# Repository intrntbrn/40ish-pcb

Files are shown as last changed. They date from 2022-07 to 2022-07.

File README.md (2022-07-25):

40-ish (a Bakeneko60 fork)
==================

<p align="center">
  
</p>

<p align="center">
  
</p>

<p align="center">
  
</p>

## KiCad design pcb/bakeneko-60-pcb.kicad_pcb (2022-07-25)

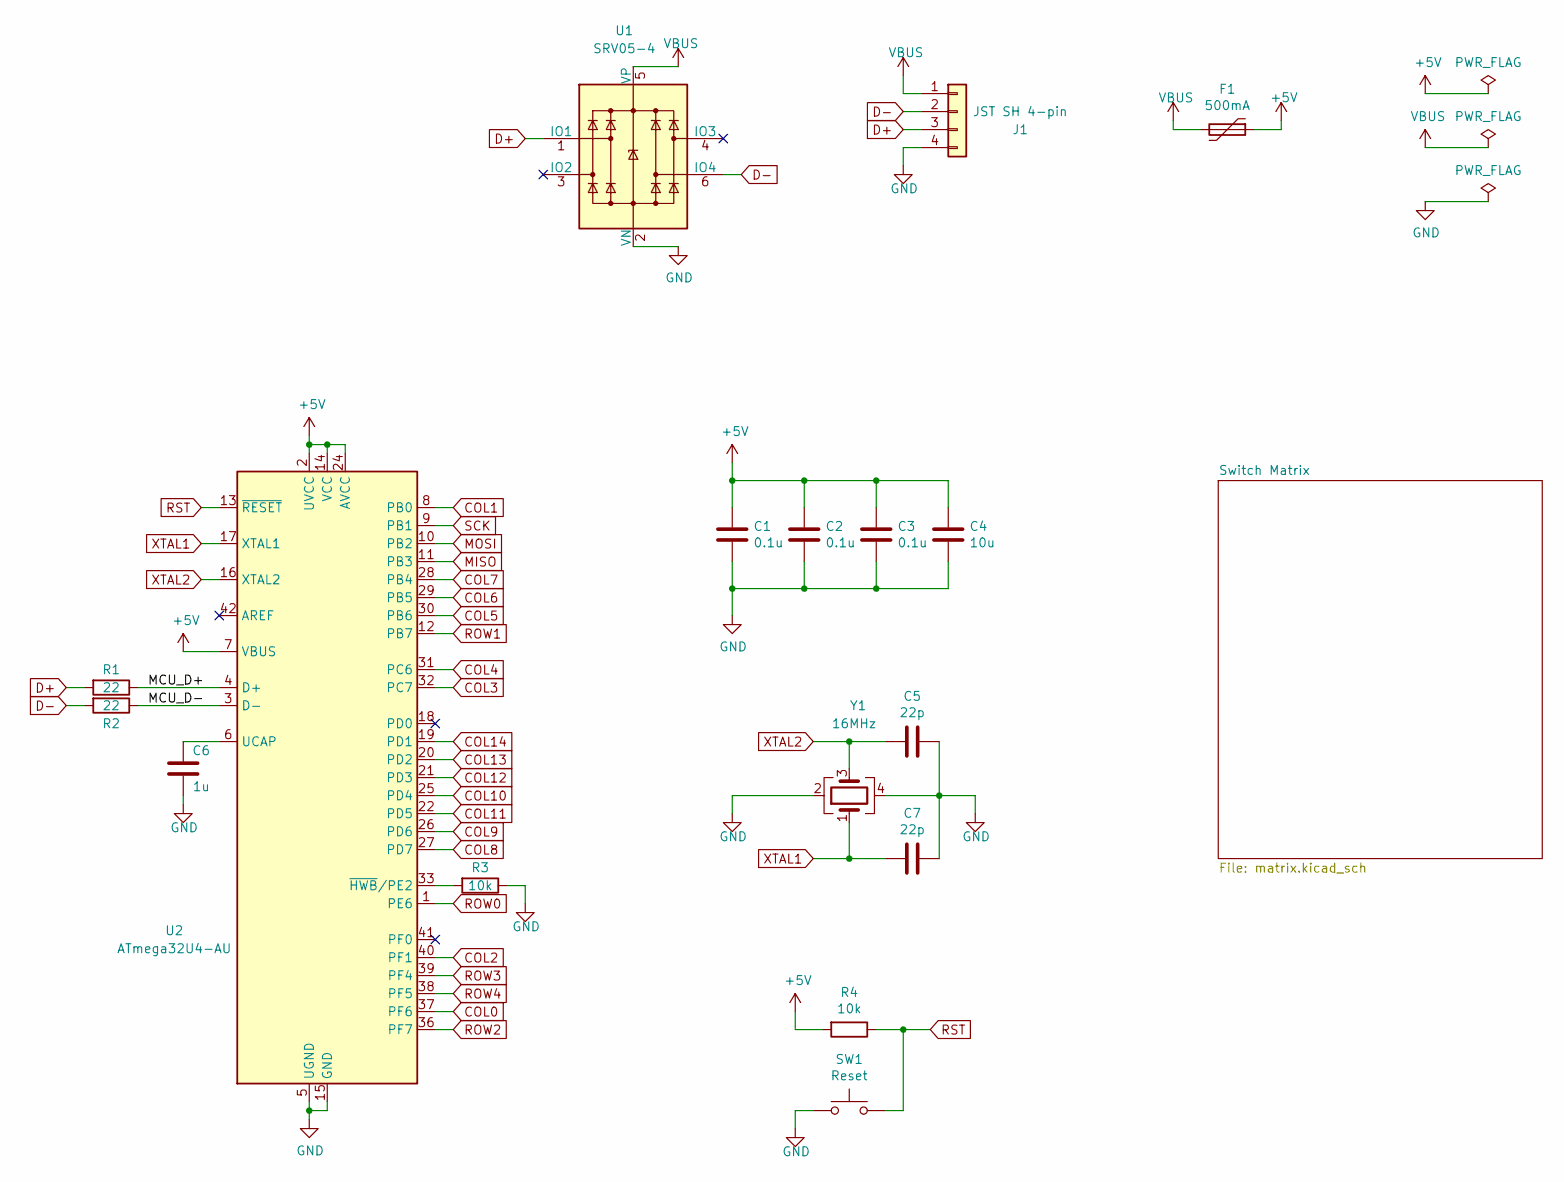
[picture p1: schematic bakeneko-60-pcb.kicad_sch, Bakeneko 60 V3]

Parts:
C1, C2, C3: 0.1u; C_0805_2012Metric; LCSC Part # C49678
C4: 10u; C_0805_2012Metric; LCSC Part # C15850
C5, C7: 22p; C_0805_2012Metric; LCSC Part # C1804
C6: 1u; C_0805_2012Metric; LCSC Part # C28323
F1: 500mA; Fuse_1206_3216Metric; LCSC Part # C70076
J1: JST SH 4-pin; JST_SH_SM04B-SRSS-TB_1x04-1MP_P1.00mm_Horizontal; LCSC Part # C160404
R1, R2: 22; R_0805_2012Metric; LCSC Part # C17561
R3, R4: 10k; R_0805_2012Metric; LCSC Part # C17414
SW1: Reset; SW_SPST_TL3342; LCSC Part # C318884
U1: SRV05-4; SOT-23-6; LCSC Part # C85364
U2: ATmega32U4-AU; TQFP-44_10x10mm_P0.8mm; LCSC Part # C44854
Y1: 16MHz; Crystal_SMD_3225-4Pin_3.2x2.5mm; LCSC Part # C13738

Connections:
+5V: C1.1, C2.1, C3.1, C4.1, F1.1, R4.2, U2.2 (UVCC), U2.7 (VBUS), U2.14 (VCC), U2.24 (AVCC), U2.34 (VCC), U2.44 (AVCC)
/MCU_D+: R1.1, U2.4 (D+)
/MCU_D-: R2.1, U2.3 (D-)
COL0: U2.37 (PF6); also elsewhere on the board
COL1: U2.8 (PB0); also elsewhere on the board
COL2: U2.40 (PF1); also elsewhere on the board
COL3: U2.32 (PC7); also elsewhere on the board
COL4: U2.31 (PC6); also elsewhere on the board
COL5: U2.30 (PB6); also elsewhere on the board
COL6: U2.29 (PB5); also elsewhere on the board
COL7: U2.28 (PB4); also elsewhere on the board
COL8: U2.27 (PD7); also elsewhere on the board
COL9: U2.26 (PD6); also elsewhere on the board
COL10: U2.25 (PD4); also elsewhere on the board
COL11: U2.22 (PD5); also elsewhere on the board
COL12: U2.21 (PD3); also elsewhere on the board
COL13: U2.20 (PD2); also elsewhere on the board
COL14: U2.19 (PD1); also elsewhere on the board
D+: J1.3, R1.2, U1.1 (IO1)
D-: J1.2, R2.2, U1.6 (IO4)
GND: C1.2, C2.2, C3.2, C4.2, C5.1, C6.2, C7.1, J1.4, R3.1, SW1.1, U1.2 (VN), U2.5 (UGND), U2.15 (GND), U2.23 (GND), U2.35 (GND), U2.43 (GND), Y1.2, Y1.4
MISO: U2.11 (PB3)
MOSI: U2.10 (PB2)
unnamed: C6.1, U2.6 (UCAP)
unnamed: R3.2, U2.33 (~HWB/PE2)
ROW0: U2.1 (PE6); also elsewhere on the board
ROW1: U2.12 (PB7); also elsewhere on the board
ROW2: U2.36 (PF7); also elsewhere on the board
ROW3: U2.39 (PF4); also elsewhere on the board
ROW4: U2.38 (PF5); also elsewhere on the board
RST: R4.1, SW1.2, U2.13 (~RESET)
SCK: U2.9 (PB1)
VBUS: F1.2, J1.1, U1.5 (VP)
XTAL1: C7.2, U2.17 (XTAL1), Y1.1
XTAL2: C5.2, U2.16 (XTAL2), Y1.3

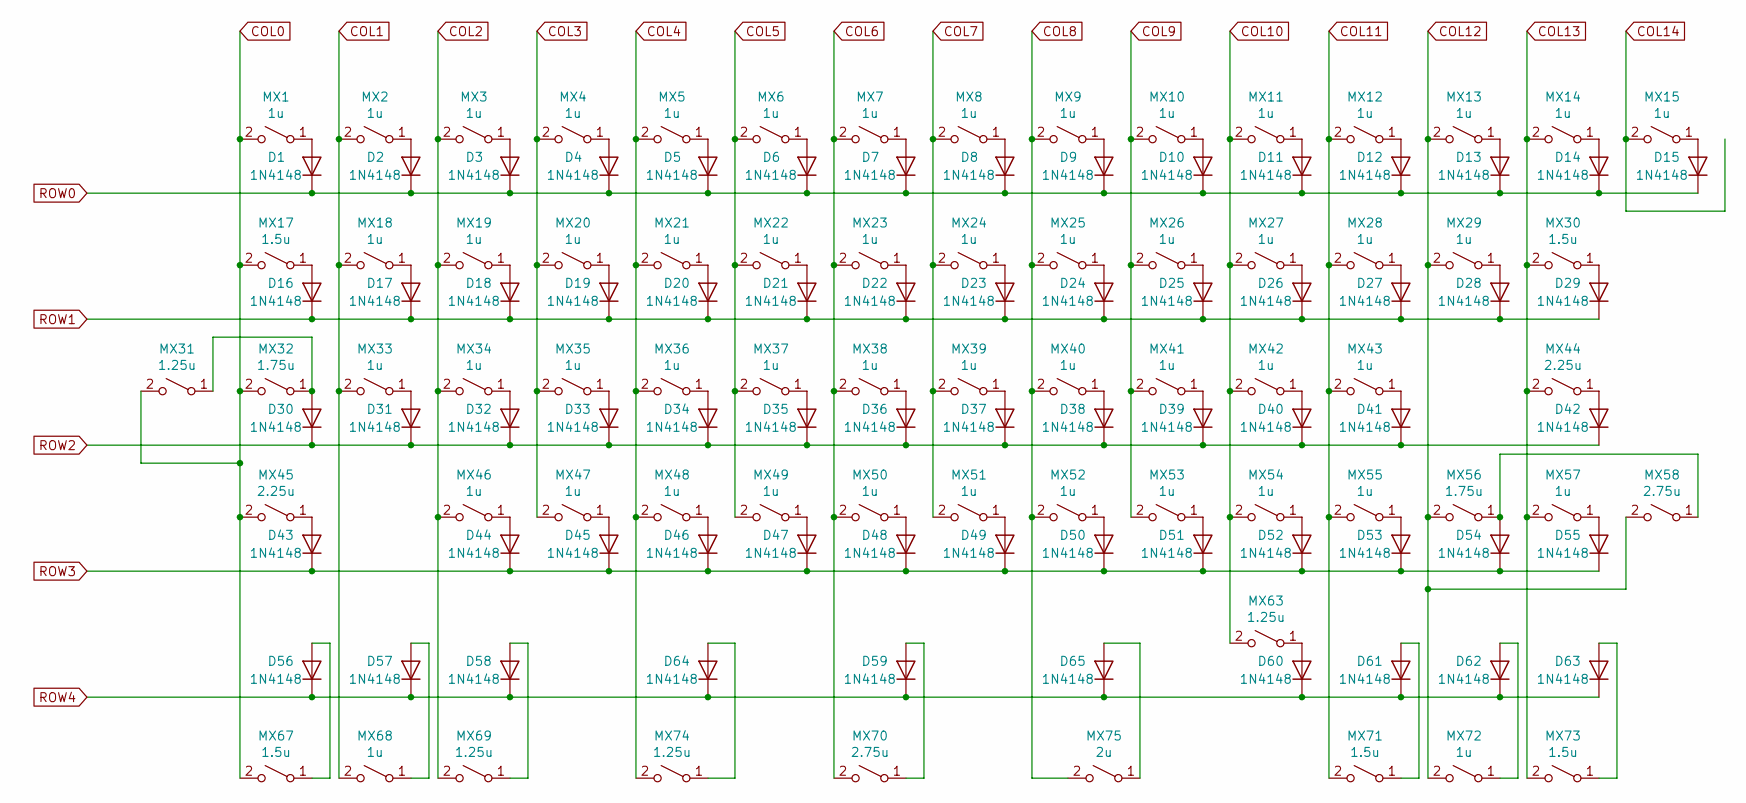
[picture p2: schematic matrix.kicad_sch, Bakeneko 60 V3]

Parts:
D1, D2, D3, D4, D5, D6, D7, D8, D9, D10, D11, D12, D13, D14, D15, D16, D17, D18, D19, D20, D21, D22, D23, D24, D25, D26, D27, D28, D29, D30, D31, D32, D33, D34, D35, D36, D37, D38, D39, D40, D41, D42, D43, D44, D45, D46, D47, D48, D49, D50, D51, D52, D53, D54, D55, D56, D57, D58, D59, D60, D61, D62, D63, D64, D65: 1N4148; D_SOD-123; LCSC Part # C81598
MX1, MX2, MX3, MX4, MX5, MX6, MX7, MX8, MX9, MX10, MX11, MX12, MX13, MX14, MX15, MX18, MX19, MX20, MX21, MX22, MX23, MX24, MX25, MX26, MX27, MX28, MX29, MX33, MX34, MX35, MX36, MX37, MX38, MX39, MX40, MX41, MX42, MX43, MX46, MX47, MX48, MX49, MX50, MX51, MX52, MX53, MX54, MX55, MX57, MX68, MX72: 1u; MXOnly-1U-NoLED
MX17, MX30, MX67, MX71, MX73: 1.5u; MXOnly-1.5U-NoLED
MX31, MX63, MX69, MX74: 1.25u; MXOnly-1.25U-NoLED
MX32, MX56: 1.75u; MXOnly-1.75U-NoLED
MX44, MX45: 2.25u; MXOnly-2.25U-NoLED
MX58: 2.75u; MXOnly-2.75U-NoLED
MX70: 2.75u; MXOnly-2.75U-ReversedStabilizers-NoLED
MX75: 2u; MXOnly-2U-ReversedStabilizers-NoLED

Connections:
COL0: MX1.2 (B), MX17.2 (B), MX31.2 (B), MX32.2 (B), MX45.2 (B), MX67.2 (B); also elsewhere on the board
COL1: MX2.2 (B), MX18.2 (B), MX33.2 (B), MX68.2 (B); also elsewhere on the board
COL2: MX3.2 (B), MX19.2 (B), MX34.2 (B), MX46.2 (B), MX69.2 (B); also elsewhere on the board
COL3: MX4.2 (B), MX20.2 (B), MX35.2 (B), MX47.2 (B); also elsewhere on the board
COL4: MX5.2 (B), MX21.2 (B), MX36.2 (B), MX48.2 (B), MX74.2 (B); also elsewhere on the board
COL5: MX6.2 (B), MX22.2 (B), MX37.2 (B), MX49.2 (B); also elsewhere on the board
COL6: MX7.2 (B), MX23.2 (B), MX38.2 (B), MX50.2 (B), MX70.2 (B); also elsewhere on the board
COL7: MX8.2 (B), MX24.2 (B), MX39.2 (B), MX51.2 (B); also elsewhere on the board
COL8: MX9.2 (B), MX25.2 (B), MX40.2 (B), MX52.2 (B), MX75.2 (B); also elsewhere on the board
COL9: MX10.2 (B), MX26.2 (B), MX41.2 (B), MX53.2 (B); also elsewhere on the board
COL10: MX11.2 (B), MX27.2 (B), MX42.2 (B), MX54.2 (B), MX63.2 (B); also elsewhere on the board
COL11: MX12.2 (B), MX28.2 (B), MX43.2 (B), MX55.2 (B), MX71.2 (B); also elsewhere on the board
COL12: MX13.2 (B), MX29.2 (B), MX56.2 (B), MX58.2 (B), MX72.2 (B); also elsewhere on the board
COL13: MX14.2 (B), MX30.2 (B), MX44.2 (B), MX57.2 (B), MX73.2 (B); also elsewhere on the board
COL14: MX15.2 (B); also elsewhere on the board
unnamed: D1.2 (A), MX1.1 (A)
unnamed: D2.2 (A), MX2.1 (A)
unnamed: D3.2 (A), MX3.1 (A)
unnamed: D4.2 (A), MX4.1 (A)
unnamed: D5.2 (A), MX5.1 (A)
unnamed: D6.2 (A), MX6.1 (A)
unnamed: D7.2 (A), MX7.1 (A)
unnamed: D8.2 (A), MX8.1 (A)
unnamed: D9.2 (A), MX9.1 (A)
unnamed: D10.2 (A), MX10.1 (A)
unnamed: D11.2 (A), MX11.1 (A)
unnamed: D12.2 (A), MX12.1 (A)
unnamed: D13.2 (A), MX13.1 (A)
unnamed: D14.2 (A), MX14.1 (A)
unnamed: D15.2 (A), MX15.1 (A)
unnamed: D16.2 (A), MX17.1 (A)
unnamed: D17.2 (A), MX18.1 (A)
unnamed: D18.2 (A), MX19.1 (A)
unnamed: D19.2 (A), MX20.1 (A)
unnamed: D20.2 (A), MX21.1 (A)
unnamed: D21.2 (A), MX22.1 (A)
unnamed: D22.2 (A), MX23.1 (A)
unnamed: D23.2 (A), MX24.1 (A)
unnamed: D24.2 (A), MX25.1 (A)
unnamed: D25.2 (A), MX26.1 (A)
unnamed: D26.2 (A), MX27.1 (A)
unnamed: D27.2 (A), MX28.1 (A)
unnamed: D28.2 (A), MX29.1 (A)
unnamed: D29.2 (A), MX30.1 (A)
unnamed: D30.2 (A), MX31.1 (A), MX32.1 (A)
unnamed: D31.2 (A), MX33.1 (A)
unnamed: D32.2 (A), MX34.1 (A)
unnamed: D33.2 (A), MX35.1 (A)
unnamed: D34.2 (A), MX36.1 (A)
unnamed: D35.2 (A), MX37.1 (A)
unnamed: D36.2 (A), MX38.1 (A)
unnamed: D37.2 (A), MX39.1 (A)
unnamed: D38.2 (A), MX40.1 (A)
unnamed: D39.2 (A), MX41.1 (A)
unnamed: D40.2 (A), MX42.1 (A)
unnamed: D41.2 (A), MX43.1 (A)
unnamed: D42.2 (A), MX44.1 (A)
unnamed: D43.2 (A), MX45.1 (A)
unnamed: D44.2 (A), MX46.1 (A)
unnamed: D45.2 (A), MX47.1 (A)
unnamed: D46.2 (A), MX48.1 (A)
unnamed: D47.2 (A), MX49.1 (A)
unnamed: D48.2 (A), MX50.1 (A)
unnamed: D49.2 (A), MX51.1 (A)
unnamed: D50.2 (A), MX52.1 (A)
unnamed: D51.2 (A), MX53.1 (A)
unnamed: D52.2 (A), MX54.1 (A)
unnamed: D53.2 (A), MX55.1 (A)
unnamed: D54.2 (A), MX56.1 (A), MX58.1 (A)
unnamed: D55.2 (A), MX57.1 (A)
unnamed: D56.2 (A), MX67.1 (A)
unnamed: D57.2 (A), MX68.1 (A)
unnamed: D58.2 (A), MX69.1 (A)
unnamed: D59.2 (A), MX70.1 (A)
unnamed: D60.2 (A), MX63.1 (A)
unnamed: D61.2 (A), MX71.1 (A)
unnamed: D62.2 (A), MX72.1 (A)
unnamed: D63.2 (A), MX73.1 (A)
unnamed: D64.2 (A), MX74.1 (A)
unnamed: D65.2 (A), MX75.1 (A)
ROW0: D1.1 (K), D2.1 (K), D3.1 (K), D4.1 (K), D5.1 (K), D6.1 (K), D7.1 (K), D8.1 (K), D9.1 (K), D10.1 (K), D11.1 (K), D12.1 (K), D13.1 (K), D14.1 (K), D15.1 (K); also elsewhere on the board
ROW1: D16.1 (K), D17.1 (K), D18.1 (K), D19.1 (K), D20.1 (K), D21.1 (K), D22.1 (K), D23.1 (K), D24.1 (K), D25.1 (K), D26.1 (K), D27.1 (K), D28.1 (K), D29.1 (K); also elsewhere on the board
ROW2: D30.1 (K), D31.1 (K), D32.1 (K), D33.1 (K), D34.1 (K), D35.1 (K), D36.1 (K), D37.1 (K), D38.1 (K), D39.1 (K), D40.1 (K), D41.1 (K), D42.1 (K); also elsewhere on the board
ROW3: D43.1 (K), D44.1 (K), D45.1 (K), D46.1 (K), D47.1 (K), D48.1 (K), D49.1 (K), D50.1 (K), D51.1 (K), D52.1 (K), D53.1 (K), D54.1 (K), D55.1 (K); also elsewhere on the board
ROW4: D56.1 (K), D57.1 (K), D58.1 (K), D59.1 (K), D60.1 (K), D61.1 (K), D62.1 (K), D63.1 (K), D64.1 (K), D65.1 (K); also elsewhere on the board

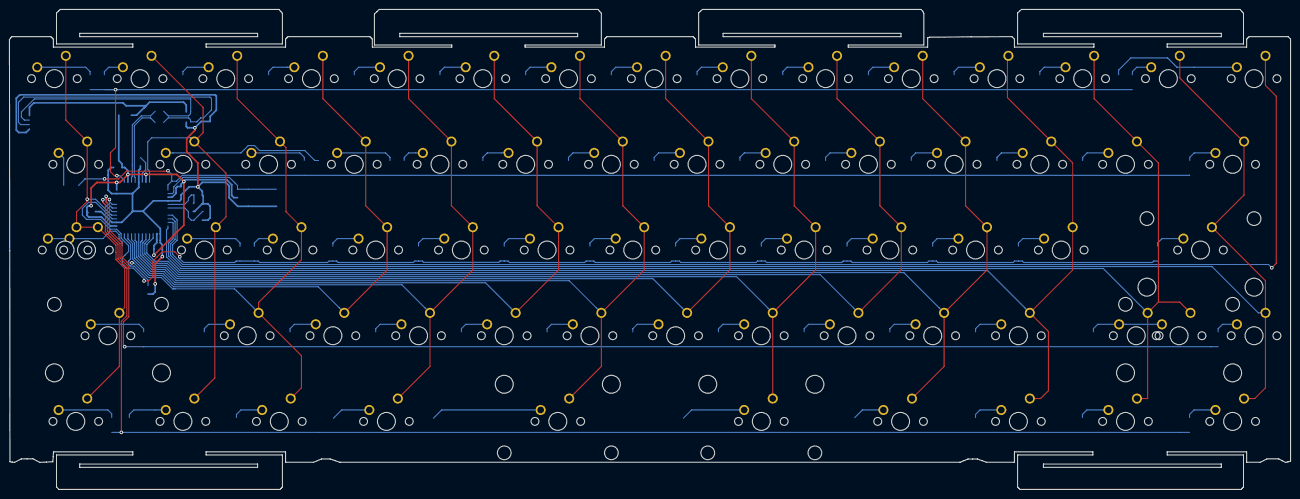
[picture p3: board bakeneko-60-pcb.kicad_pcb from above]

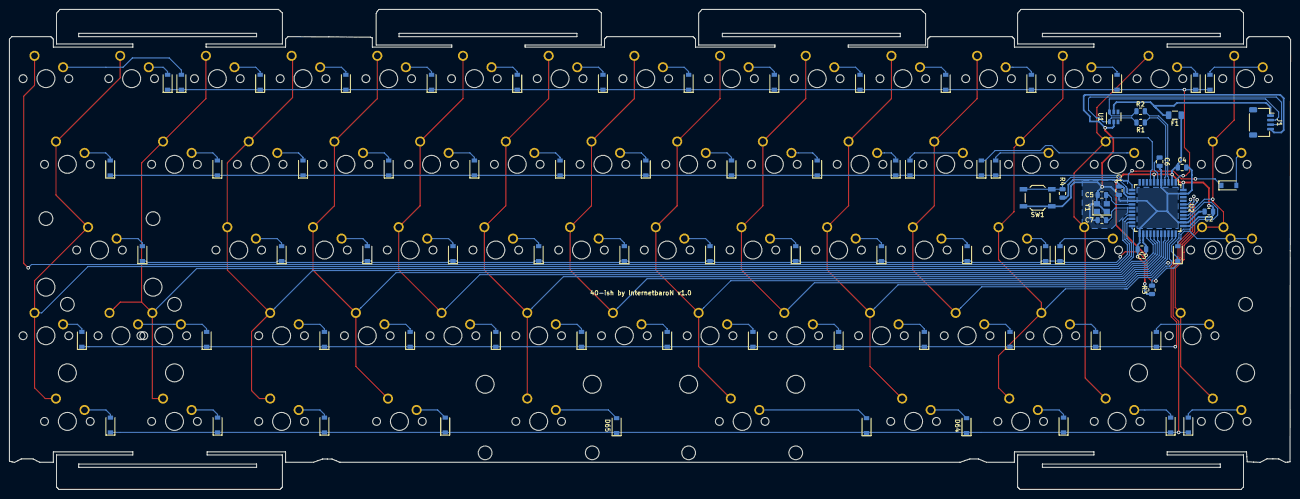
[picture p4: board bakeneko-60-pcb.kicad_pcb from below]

Board: 2 copper layers, 284.8 x 106.7 mm, 149 parts (82 on the bottom side), 97 nets.

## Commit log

2022-07-22 remove 6.25u bottom row
    [bakeneko-60-pcb.kicad_pcb, bakeneko-60-pcb.kicad_sch, matrix.kicad_sch]
2022-07-22 add fn1
    [bakeneko-60-pcb.kicad_pcb, bakeneko-60-pcb.kicad_sch, matrix.kicad_sch]
2022-07-22 bottom row done except for diodes wrong side
    [bakeneko-60-pcb.kicad_pcb, bakeneko-60-pcb.kicad_sch, matrix.kicad_sch]
2022-07-22 bottom row done
    [bakeneko-60-pcb.kicad_pcb]
2022-07-22 fix silkscreen diode text
    [bakeneko-60-pcb.kicad_pcb]
2022-07-22 all good, waiting for outline
    [bakeneko-60-pcb.kicad_pcb]
2022-07-22 cleanup readme
    [bakeneko-60-pcb.kicad_pcb]
2022-07-22 add production files
    [bakeneko-60-pcb-CuBottom.gbr, bakeneko-60-pcb-CuTop.gbr, bakeneko-60-pcb-EdgeCuts.gbr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]
2022-07-23 no corner outline
    [bakeneko-60-pcb.kicad_pcb]
2022-07-23 remove silk overlay placeholder
    [bakeneko-60-pcb.kicad_pcb]
2022-07-23 move text to center
    [bakeneko-60-pcb.kicad_pcb]
2022-07-23 corner outline fix
    [bakeneko-60-pcb.kicad_pcb]
2022-07-23 flip diode silk
    [bakeneko-60-pcb.kicad_pcb]
2022-07-23 remove 2u bs option due to leaf spring interference
    [bakeneko-60-pcb.kicad_pcb, bakeneko-60-pcb.kicad_sch, matrix.kicad_sch]
2022-07-23 pass drc checks
    [bakeneko-60-pcb.kicad_pcb, matrix.kicad_sch]
2022-07-23 align leaf spring holes properly
    [bakeneko-60-pcb.kicad_pcb]
2022-07-23 round outline corners
    [bakeneko-60-pcb.kicad_pcb]
2022-07-23 fine tune corners
    [bakeneko-60-pcb.kicad_pcb]
2022-07-23 generate production files
    [bakeneko-60-pcb-CuBottom.gbr, bakeneko-60-pcb-CuTop.gbr, bakeneko-60-pcb-EdgeCuts.gbr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]
2022-07-23 kle and pcb image
2022-07-25 move diode and make room for jst replacement
    [bakeneko-60-pcb.kicad_pcb]
2022-07-25 remove isp and connections
    [bakeneko-60-pcb.kicad_pcb, bakeneko-60-pcb.kicad_sch]
2022-07-25 move jst connector
    [bakeneko-60-pcb.kicad_pcb]
2022-07-25 micro adjust placement of jst connector
    [bakeneko-60-pcb.kicad_pcb]
2022-07-25 cleanup tracks
    [bakeneko-60-pcb.kicad_pcb]
2022-07-25 update production files
    [bakeneko-60-pcb-CuBottom.gbr, bakeneko-60-pcb-CuTop.gbr, bakeneko-60-pcb-EdgeCuts.gbr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]

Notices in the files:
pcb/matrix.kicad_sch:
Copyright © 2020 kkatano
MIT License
